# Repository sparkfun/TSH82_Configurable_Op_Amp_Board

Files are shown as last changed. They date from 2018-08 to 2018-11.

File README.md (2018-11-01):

SparkFun Configurable OpAmp Board - TSH82
========================================

SparkFun Configurable OpAmp Board - TSH82

[*SparkFun Configurable OpAmp Board - TSH82 (14874)*](https://www.sparkfun.com/products/14874)

The SparkFun TSH82 Configurable OpAmp Board was designed to give you the best combination of performance and flexibility that we could achieve by giving you two gain stages, each one independently accessible on the header pins. Each stage is natively configured as an inverting amplifier that can also be strung together to expand the capabilities of the OpAmp. With the use of the jumpers on the back of the board, you can configure each stage for non-inverting operation, differential input, and DC input coupling.

Electrically speaking, both stages on this board are identical. The default configuration is inverting with a gain of -4.7 with a bandwidth of almost 10MHz. Input signals are AC coupled, possess an input impedance of 10K with a low frequency cutoff of 15.9Hz. Outputs are also DC coupled, so don’t forget to add a capacitor to the output if you’re running a single-ended supply and need to strip out the DC component. The board will also operate with a single-ended DC power supply of 4.5V to 12V, or a bipolar supply from +/-2.25V to +/-6V.

On the back of the board you’ll find 10 solder jumpers that can be used to change the board’s performance, but nothing there needs to be changed to use it in it’s default state.

Repository Contents
-------------------
* **/Hardware** - Eagle design files (.brd, .sch)
* **/Production** - Production panel files (.brd)

Documentation
--------------
* **[Hookup Guide](https://learn.sparkfun.com/tutorials/tsh82-configurable-opamp-hookup-guide)** - Basic hookup guide for the SparkFun Configurable OpAmp Board - TSH82.
* **[SparkFun Fritzing repo](https://github.com/sparkfun/Fritzing_Parts)** - Fritzing diagrams for SparkFun products.

License Information
-------------------

This product is _**open source**_! 

Please review the LICENSE.md file for license information. 

If you have any questions or concerns on licensing, please contact techsupport@sparkfun.com.

Distributed as-is; no warranty is given.

- Your friends at SparkFun.

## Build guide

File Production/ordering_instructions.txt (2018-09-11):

panel size, 201x143mm
PCB thickness, 1.6mm
number of layers, 2
soldermask color, Red
silkscreen color, White
oz copper, 1oz
finish, HASL lead free
stencils, none
pcs per panel, 40

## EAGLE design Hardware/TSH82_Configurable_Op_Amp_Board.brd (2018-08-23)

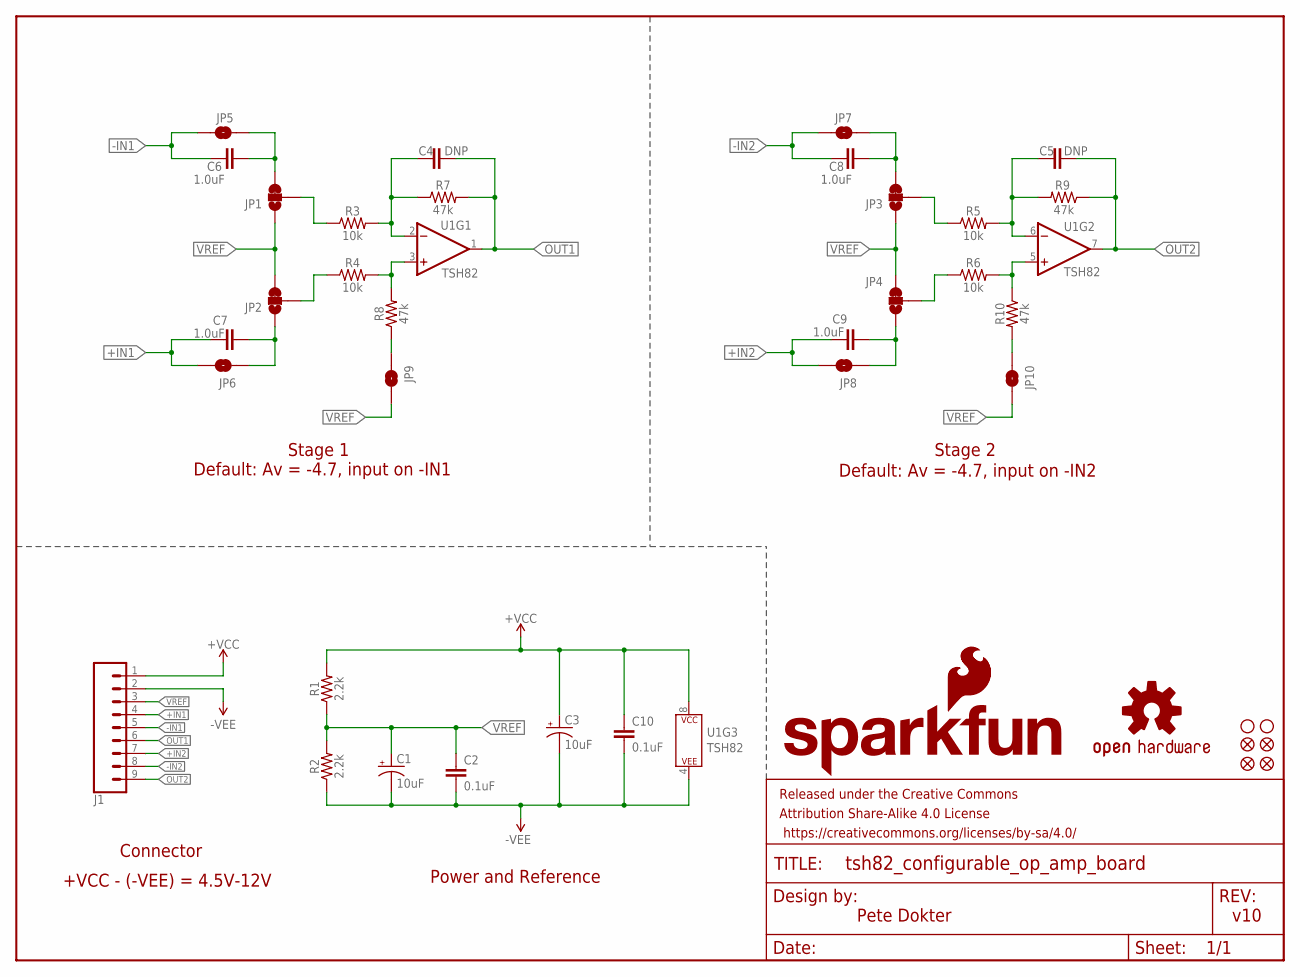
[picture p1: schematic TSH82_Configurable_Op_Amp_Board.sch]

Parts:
C1, C3: 10uF; EIA3216
C2, C10: 0.1uF; 0603
C4, C5: DNP; 0603
C6, C7, C8, C9: 1.0uF; 0603
FD1, FD2, FD3, FD4: FIDUCIALUFIDUCIAL; FIDUCIAL-MICRO
FRAME1: FRAME-LETTER; CREATIVE_COMMONS
H1, H2: STAND-OFF
J1: CONN_09NO_SILK; 1X09_NO_SILK
JP1, JP2, JP3, JP4: JUMPER-SMT_3_1-NC_TRACE_SILK; SMT-JUMPER_3_1-NC_TRACE_SILK
JP5, JP6, JP7, JP8, JP9, JP10: JUMPER-SMT_2_NO_SILK; SMT-JUMPER_2_NO_SILK
LOGO1: SFE_LOGO_FLAME.2_INCH; SFE_LOGO_FLAME_.2
LOGO2: SFE_LOGO_NAME_FLAME.1_INCH; SFE_LOGO_NAME_FLAME_.1
LOGO3: OSHW-LOGOS; OSHW-LOGO-S
R1, R2: 2.2k; 0603
R3, R4, R5, R6: 10k; 0603
R7, R8, R9, R10: 47k; 0603
U1: TSH82; SO08

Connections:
+IN1: C7.1, J1.4, JP6.2
+IN2: C9.1, J1.7, JP8.2
-IN1: C6.1, J1.5, JP5.2
-IN2: C8.1, J1.8, JP7.2
unnamed: C4.1, R3.2, R7.1, U1.2 (-IN)
unnamed: R4.2, R8.2, U1.3 (+IN)
unnamed: JP9.1, R8.1
unnamed: JP1.2, R3.1
unnamed: JP2.2, R4.1
unnamed: C6.2, JP1.3, JP5.1
unnamed: C7.2, JP2.1, JP6.1
unnamed: C8.2, JP3.3, JP7.1
unnamed: JP3.2, R5.1
unnamed: C5.1, R5.2, R9.2, U1.6 (-IN)
unnamed: JP4.2, R6.1
unnamed: C9.2, JP4.1, JP8.1
unnamed: R6.2, R10.1, U1.5 (+IN)
unnamed: JP10.1, R10.2
OUT1: C4.2, J1.6, R7.2, U1.1 (OUT)
OUT2: C5.2, J1.9, R9.1, U1.7 (OUT)
VCC: C3.+, C10.1, J1.1, R1.2, U1.8 (P$V+)
VNEG: C1.-, C2.2, C3.-, C10.2, J1.2, R2.1, U1.4 (P$V-)
VREF: C1.+, C2.1, J1.3, JP1.1, JP2.3, JP3.1, JP4.3, JP9.2, JP10.2, R1.1, R2.2

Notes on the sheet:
Stage 1
Default: Av = -4.7, input on -IN1
Default: Av = -4.7, input on -IN2
Stage 2
Pete Dokter
Connector
Power and Reference
v10
+VCC - (-VEE) = 4.5V-12V

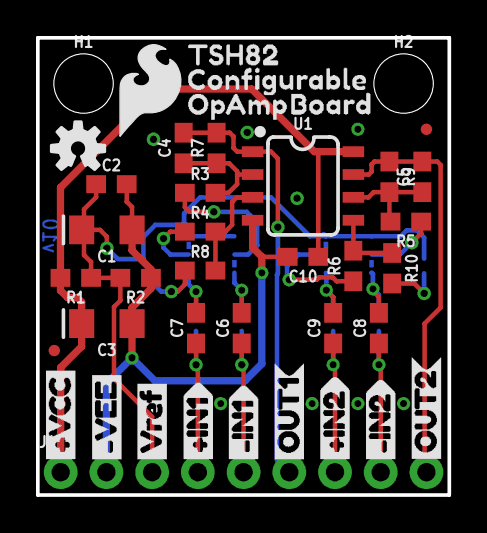
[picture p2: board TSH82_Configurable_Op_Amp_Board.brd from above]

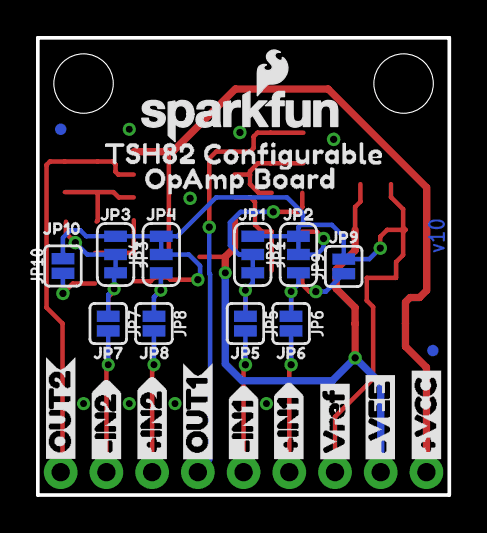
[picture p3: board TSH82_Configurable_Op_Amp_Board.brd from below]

Board: 2 copper layers, 22.9 x 25.4 mm, 78 parts (36 on the bottom side), 23 nets.

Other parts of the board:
U$1, U$2: #VEE1
U$3, U$30: #VCC0
U$4, U$5: VREF6
U$6, U$7: #IN12
U$8, U$9: #IN13
U$10, U$11: OUT17
U$12, U$13: #IN24
U$14, U$16: #IN25
U$15, U$17: OUT28
U$18: JP10
U$19: JP21
U$20: JP32
U$21: JP43
U$22, U$26: TSH820
U$23, U$27: CONFIGURABLE1
U$24, U$28: OPAMP2
U$25, U$29: BOARD3
U$31: JP54
U$32: JP65
U$33: JP76
U$34: JP87
U$35: JP98
U$36: JP109

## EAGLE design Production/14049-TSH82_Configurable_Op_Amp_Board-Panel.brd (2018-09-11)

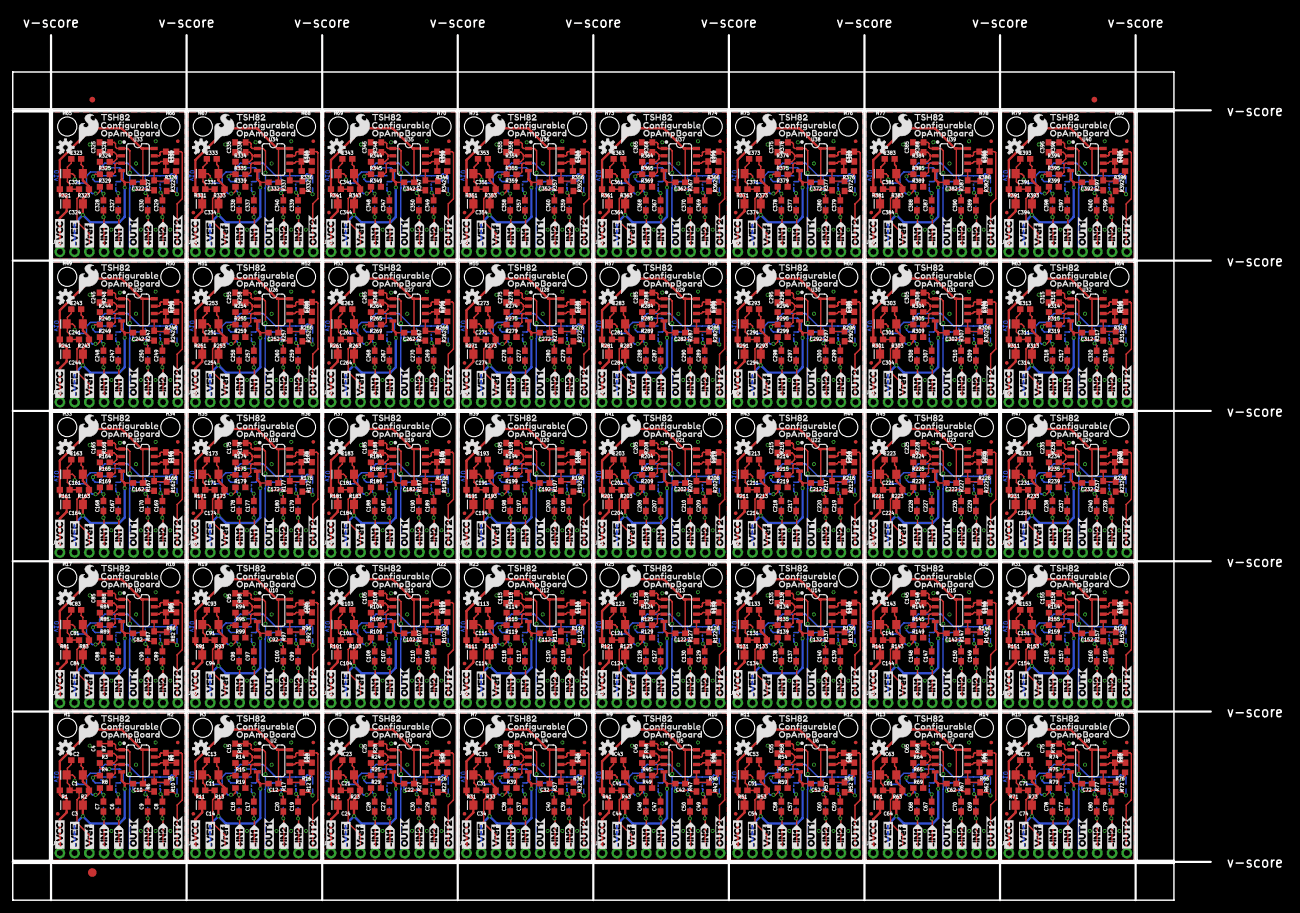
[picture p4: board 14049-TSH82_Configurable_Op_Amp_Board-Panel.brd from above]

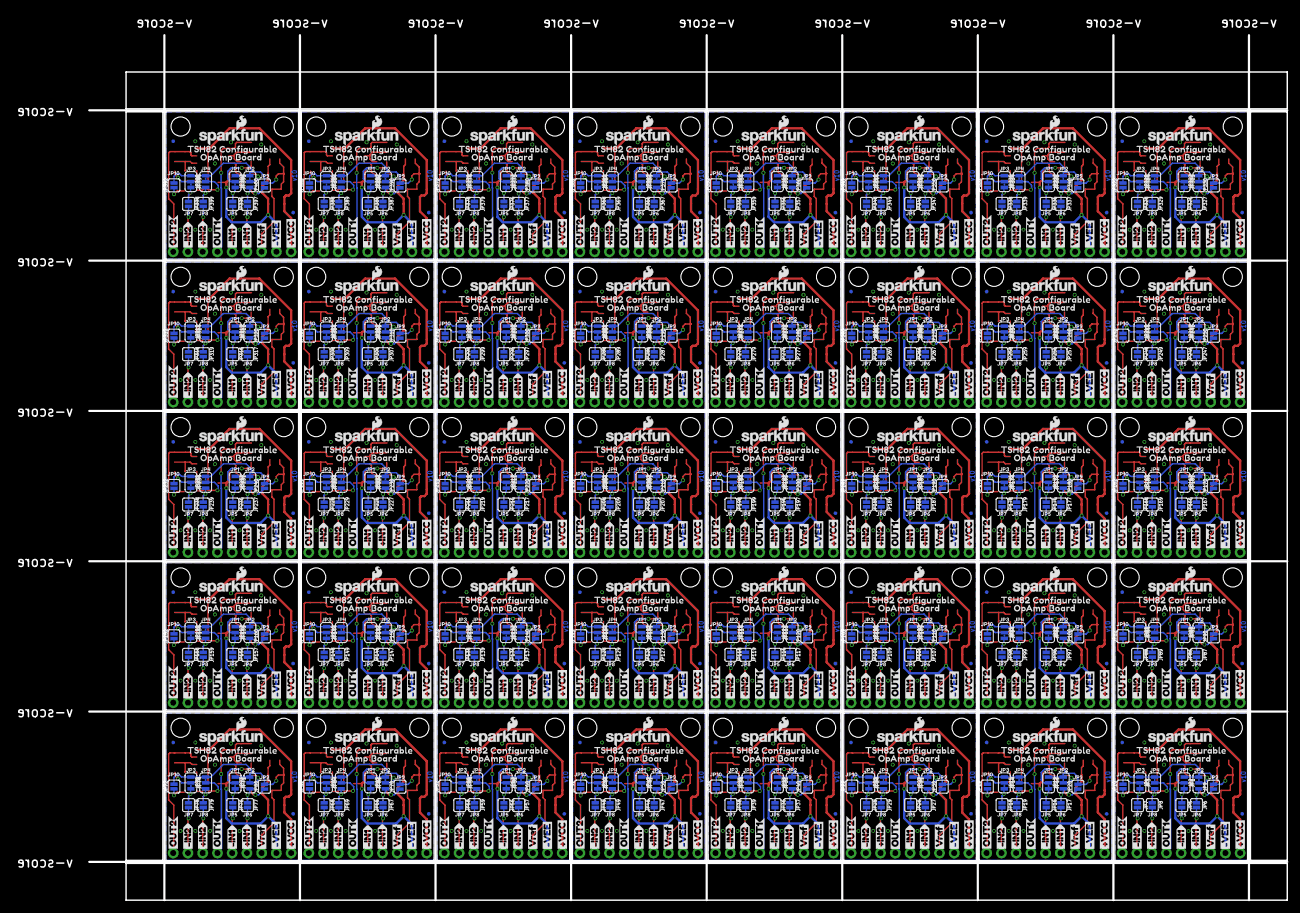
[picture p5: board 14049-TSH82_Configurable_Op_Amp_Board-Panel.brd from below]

Board: 2 copper layers, 206.5 x 149.1 mm, 3083 parts (1440 on the bottom side), 920 nets.

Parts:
C1, C3, C11, C14, C21, C24, C31, C34, C41, C44, C51, C54, C61, C64, C71, C74, C81, C84, C91, C94, C101, C104, C111, C114, C121, C124, C131, C134, C141, C144, C151, C154, C161, C164, C171, C174, C181, C184, C191, C194, C201, C204, C211, C214, C221, C224, C231, C234, C241, C244, C251, C254, C261, C264, C271, C274, C281, C284, C291, C294, C301, C304, C311, C314, C321, C324, C331, C334, C341, C344, C351, C354, C361, C364, C371, C374, C381, C384, C391, C394: 10uF; EIA3216
C2, C10, C12, C13, C22, C23, C32, C33, C42, C43, C52, C53, C62, C63, C72, C73, C82, C83, C92, C93, C102, C103, C112, C113, C122, C123, C132, C133, C142, C143, C152, C153, C162, C163, C172, C173, C182, C183, C192, C193, C202, C203, C212, C213, C222, C223, C232, C233, C242, C243, C252, C253, C262, C263, C272, C273, C282, C283, C292, C293, C302, C303, C312, C313, C322, C323, C332, C333, C342, C343, C352, C353, C362, C363, C372, C373, C382, C383, C392, C393: 0.1uF; 0603
C4, C5, C15, C16, C25, C26, C35, C36, C45, C46, C55, C56, C65, C66, C75, C76, C85, C86, C95, C96, C105, C106, C115, C116, C125, C126, C135, C136, C145, C146, C155, C156, C165, C166, C175, C176, C185, C186, C195, C196, C205, C206, C215, C216, C225, C226, C235, C236, C245, C246, C255, C256, C265, C266, C275, C276, C285, C286, C295, C296, C305, C306, C315, C316, C325, C326, C335, C336, C345, C346, C355, C356, C365, C366, C375, C376, C385, C386, C395, C396: DNP; 0603
C6, C7, C8, C9, C17, C18, C19, C20, C27, C28, C29, C30, C37, C38, C39, C40, C47, C48, C49, C50, C57, C58, C59, C60, C67, C68, C69, C70, C77, C78, C79, C80, C87, C88, C89, C90, C97, C98, C99, C100, C107, C108, C109, C110, C117, C118, C119, C120, C127, C128, C129, C130, C137, C138, C139, C140, C147, C148, C149, C150, C157, C158, C159, C160, C167, C168, C169, C170, C177, C178, C179, C180, C187, C188, C189, C190, C197, C198, C199, C200, C207, C208, C209, C210, C217, C218, C219, C220, C227, C228, C229, C230, C237, C238, C239, C240, C247, C248, C249, C250, C257, C258, C259, C260, C267, C268, C269, C270, C277, C278, C279, C280, C287, C288, C289, C290, C297, C298, C299, C300, C307, C308, C309, C310, C317, C318, C319, C320, C327, C328, C329, C330, C337, C338, C339, C340, C347, C348, C349, C350, C357, C358, C359, C360, C367, C368, C369, C370, C377, C378, C379, C380, C387, C388, C389, C390, C397, C398, C399, C400: 1.0uF; 0603
E$1, E$2: FIDUCIAL-1X2
E$3: FIDUCIAL-1.5X3
FD1, FD2, FD3, FD4, FD5, FD6, FD7, FD8, FD9, FD10, FD11, FD12, FD13, FD14, FD15, FD16, FD17, FD18, FD19, FD20, FD21, FD22, FD23, FD24, FD25, FD26, FD27, FD28, FD29, FD30, FD31, FD32, FD33, FD34, FD35, FD36, FD37, FD38, FD39, FD40, FD41, FD42, FD43, FD44, FD45, FD46, FD47, FD48, FD49, FD50, FD51, FD52, FD53, FD54, FD55, FD56, FD57, FD58, FD59, FD60, FD61, FD62, FD63, FD64, FD65, FD66, FD67, FD68, FD69, FD70, FD71, FD72, FD73, FD74, FD75, FD76, FD77, FD78, FD79, FD80, FD81, FD82, FD83, FD84, FD85, FD86, FD87, FD88, FD89, FD90, FD91, FD92, FD93, FD94, FD95, FD96, FD97, FD98, FD99, FD100, FD101, FD102, FD103, FD104, FD105, FD106, FD107, FD108, FD109, FD110, FD111, FD112, FD113, FD114, FD115, FD116, FD117, FD118, FD119, FD120, FD121, FD122, FD123, FD124, FD125, FD126, FD127, FD128, FD129, FD130, FD131, FD132, FD133, FD134, FD135, FD136, FD137, FD138, FD139, FD140, FD141, FD142, FD143, FD144, FD145, FD146, FD147, FD148, FD149, FD150, FD151, FD152, FD153, FD154, FD155, FD156, FD157, FD158, FD159, FD160: FIDUCIALUFIDUCIAL; FIDUCIAL-MICRO
H1, H2, H3, H4, H5, H6, H7, H8, H9, H10, H11, H12, H13, H14, H15, H16, H17, H18, H19, H20, H21, H22, H23, H24, H25, H26, H27, H28, H29, H30, H31, H32, H33, H34, H35, H36, H37, H38, H39, H40, H41, H42, H43, H44, H45, H46, H47, H48, H49, H50, H51, H52, H53, H54, H55, H56, H57, H58, H59, H60, H61, H62, H63, H64, H65, H66, H67, H68, H69, H70, H71, H72, H73, H74, H75, H76, H77, H78, H79, H80: STAND-OFF
J1, J2, J3, J4, J5, J6, J7, J8, J9, J10, J11, J12, J13, J14, J15, J16, J17, J18, J19, J20, J21, J22, J23, J24, J25, J26, J27, J28, J29, J30, J31, J32, J33, J34, J35, J36, J37, J38, J39, J40: 1X09_NO_SILK
JP1, JP2, JP3, JP4, JP11, JP13, JP14, JP15, JP21, JP23, JP24, JP25, JP31, JP33, JP34, JP35, JP41, JP43, JP44, JP45, JP51, JP53, JP54, JP55, JP61, JP63, JP64, JP65, JP71, JP73, JP74, JP75, JP81, JP83, JP84, JP85, JP91, JP93, JP94, JP95, JP101, JP103, JP104, JP105, JP111, JP113, JP114, JP115, JP121, JP123, JP124, JP125, JP131, JP133, JP134, JP135, JP141, JP143, JP144, JP145, JP151, JP153, JP154, JP155, JP161, JP163, JP164, JP165, JP171, JP173, JP174, JP175, JP181, JP183, JP184, JP185, JP191, JP193, JP194, JP195, JP201, JP203, JP204, JP205, JP211, JP213, JP214, JP215, JP221, JP223, JP224, JP225, JP231, JP233, JP234, JP235, JP241, JP243, JP244, JP245, JP251, JP253, JP254, JP255, JP261, JP263, JP264, JP265, JP271, JP273, JP274, JP275, JP281, JP283, JP284, JP285, JP291, JP293, JP294, JP295, JP301, JP303, JP304, JP305, JP311, JP313, JP314, JP315, JP321, JP323, JP324, JP325, JP331, JP333, JP334, JP335, JP341, JP343, JP344, JP345, JP351, JP353, JP354, JP355, JP361, JP363, JP364, JP365, JP371, JP373, JP374, JP375, JP381, JP383, JP384, JP385, JP391, JP393, JP394, JP395: JUMPER-SMT_3_1-NC_TRACE_SILK; SMT-JUMPER_3_1-NC_TRACE_SILK
JP5, JP6, JP7, JP8, JP9, JP10, JP12, JP16, JP17, JP18, JP19, JP20, JP22, JP26, JP27, JP28, JP29, JP30, JP32, JP36, JP37, JP38, JP39, JP40, JP42, JP46, JP47, JP48, JP49, JP50, JP52, JP56, JP57, JP58, JP59, JP60, JP62, JP66, JP67, JP68, JP69, JP70, JP72, JP76, JP77, JP78, JP79, JP80, JP82, JP86, JP87, JP88, JP89, JP90, JP92, JP96, JP97, JP98, JP99, JP100, JP102, JP106, JP107, JP108, JP109, JP110, JP112, JP116, JP117, JP118, JP119, JP120, JP122, JP126, JP127, JP128, JP129, JP130, JP132, JP136, JP137, JP138, JP139, JP140, JP142, JP146, JP147, JP148, JP149, JP150, JP152, JP156, JP157, JP158, JP159, JP160, JP162, JP166, JP167, JP168, JP169, JP170, JP172, JP176, JP177, JP178, JP179, JP180, JP182, JP186, JP187, JP188, JP189, JP190, JP192, JP196, JP197, JP198, JP199, JP200, JP202, JP206, JP207, JP208, JP209, JP210, JP212, JP216, JP217, JP218, JP219, JP220, JP222, JP226, JP227, JP228, JP229, JP230, JP232, JP236, JP237, JP238, JP239, JP240, JP242, JP246, JP247, JP248, JP249, JP250, JP252, JP256, JP257, JP258, JP259, JP260, JP262, JP266, JP267, JP268, JP269, JP270, JP272, JP276, JP277, JP278, JP279, JP280, JP282, JP286, JP287, JP288, JP289, JP290, JP292, JP296, JP297, JP298, JP299, JP300, JP302, JP306, JP307, JP308, JP309, JP310, JP312, JP316, JP317, JP318, JP319, JP320, JP322, JP326, JP327, JP328, JP329, JP330, JP332, JP336, JP337, JP338, JP339, JP340, JP342, JP346, JP347, JP348, JP349, JP350, JP352, JP356, JP357, JP358, JP359, JP360, JP362, JP366, JP367, JP368, JP369, JP370, JP372, JP376, JP377, JP378, JP379, JP380, JP382, JP386, JP387, JP388, JP389, JP390, JP392, JP396, JP397, JP398, JP399, JP400: JUMPER-SMT_2_NO_SILK; SMT-JUMPER_2_NO_SILK
LOGO1, LOGO4, LOGO7, LOGO10, LOGO13, LOGO16, LOGO19, LOGO22, LOGO25, LOGO28, LOGO31, LOGO34, LOGO37, LOGO40, LOGO43, LOGO46, LOGO49, LOGO52, LOGO55, LOGO58, LOGO61, LOGO64, LOGO67, LOGO70, LOGO73, LOGO76, LOGO79, LOGO82, LOGO85, LOGO88, LOGO91, LOGO94, LOGO97, LOGO100, LOGO103, LOGO106, LOGO109, LOGO112, LOGO115, LOGO118: SFE_LOGO_FLAME.2_INCH; SFE_LOGO_FLAME_.2
LOGO2, LOGO5, LOGO8, LOGO11, LOGO14, LOGO17, LOGO20, LOGO23, LOGO26, LOGO29, LOGO32, LOGO35, LOGO38, LOGO41, LOGO44, LOGO47, LOGO50, LOGO53, LOGO56, LOGO59, LOGO62, LOGO65, LOGO68, LOGO71, LOGO74, LOGO77, LOGO80, LOGO83, LOGO86, LOGO89, LOGO92, LOGO95, LOGO98, LOGO101, LOGO104, LOGO107, LOGO110, LOGO113, LOGO116, LOGO119: SFE_LOGO_NAME_FLAME.1_INCH; SFE_LOGO_NAME_FLAME_.1
LOGO3, LOGO6, LOGO9, LOGO12, LOGO15, LOGO18, LOGO21, LOGO24, LOGO27, LOGO30, LOGO33, LOGO36, LOGO39, LOGO42, LOGO45, LOGO48, LOGO51, LOGO54, LOGO57, LOGO60, LOGO63, LOGO66, LOGO69, LOGO72, LOGO75, LOGO78, LOGO81, LOGO84, LOGO87, LOGO90, LOGO93, LOGO96, LOGO99, LOGO102, LOGO105, LOGO108, LOGO111, LOGO114, LOGO117, LOGO120: OSHW-LOGOS; OSHW-LOGO-S
R1, R2, R11, R13, R21, R23, R31, R33, R41, R43, R51, R53, R61, R63, R71, R73, R81, R83, R91, R93, R101, R103, R111, R113, R121, R123, R131, R133, R141, R143, R151, R153, R161, R163, R171, R173, R181, R183, R191, R193, R201, R203, R211, R213, R221, R223, R231, R233, R241, R243, R251, R253, R261, R263, R271, R273, R281, R283, R291, R293, R301, R303, R311, R313, R321, R323, R331, R333, R341, R343, R351, R353, R361, R363, R371, R373, R381, R383, R391, R393: 2.2k; 0603
R3, R4, R5, R6, R14, R15, R16, R17, R24, R25, R26, R27, R34, R35, R36, R37, R44, R45, R46, R47, R54, R55, R56, R57, R64, R65, R66, R67, R74, R75, R76, R77, R84, R85, R86, R87, R94, R95, R96, R97, R104, R105, R106, R107, R114, R115, R116, R117, R124, R125, R126, R127, R134, R135, R136, R137, R144, R145, R146, R147, R154, R155, R156, R157, R164, R165, R166, R167, R174, R175, R176, R177, R184, R185, R186, R187, R194, R195, R196, R197, R204, R205, R206, R207, R214, R215, R216, R217, R224, R225, R226, R227, R234, R235, R236, R237, R244, R245, R246, R247, R254, R255, R256, R257, R264, R265, R266, R267, R274, R275, R276, R277, R284, R285, R286, R287, R294, R295, R296, R297, R304, R305, R306, R307, R314, R315, R316, R317, R324, R325, R326, R327, R334, R335, R336, R337, R344, R345, R346, R347, R354, R355, R356, R357, R364, R365, R366, R367, R374, R375, R376, R377, R384, R385, R386, R387, R394, R395, R396, R397: 10k; 0603
R7, R8, R9, R10, R12, R18, R19, R20, R22, R28, R29, R30, R32, R38, R39, R40, R42, R48, R49, R50, R52, R58, R59, R60, R62, R68, R69, R70, R72, R78, R79, R80, R82, R88, R89, R90, R92, R98, R99, R100, R102, R108, R109, R110, R112, R118, R119, R120, R122, R128, R129, R130, R132, R138, R139, R140, R142, R148, R149, R150, R152, R158, R159, R160, R162, R168, R169, R170, R172, R178, R179, R180, R182, R188, R189, R190, R192, R198, R199, R200, R202, R208, R209, R210, R212, R218, R219, R220, R222, R228, R229, R230, R232, R238, R239, R240, R242, R248, R249, R250, R252, R258, R259, R260, R262, R268, R269, R270, R272, R278, R279, R280, R282, R288, R289, R290, R292, R298, R299, R300, R302, R308, R309, R310, R312, R318, R319, R320, R322, R328, R329, R330, R332, R338, R339, R340, R342, R348, R349, R350, R352, R358, R359, R360, R362, R368, R369, R370, R372, R378, R379, R380, R382, R388, R389, R390, R392, R398, R399, R400: 47k; 0603
U1, U2, U3, U4, U5, U6, U7, U8, U9, U10, U11, U12, U13, U14, U15, U16, U17, U18, U19, U20, U21, U22, U23, U24, U25, U26, U27, U28, U29, U30, U31, U32, U33, U34, U35, U36, U37, U38, U39, U40: TSH82; SO08
U$1, U$2, U$46, U$47, U$82, U$83, U$118, U$119, U$154, U$155, U$190, U$191, U$226, U$227, U$262, U$263, U$298, U$299, U$334, U$335, U$370, U$371, U$406, U$407, U$442, U$443, U$478, U$479, U$514, U$515, U$550, U$551, U$586, U$587, U$622, U$623, U$658, U$659, U$694, U$695, U$730, U$731, U$766, U$767, U$802, U$803, U$838, U$839, U$874, U$875, U$910, U$911, U$946, U$947, U$982, U$983, U$1018, U$1019, U$1054, U$1055, U$1090, U$1091, U$1126, U$1127, U$1162, U$1163, U$1198, U$1199, U$1234, U$1235, U$1270, U$1271, U$1306, U$1307, U$1342, U$1343, U$1378, U$1379, U$1414, U$1415: #VEE1
U$3, U$30, U$45, U$48, U$81, U$84, U$117, U$120, U$153, U$156, U$189, U$192, U$225, U$228, U$261, U$264, U$297, U$300, U$333, U$336, U$369, U$372, U$405, U$408, U$441, U$444, U$477, U$480, U$513, U$516, U$549, U$552, U$585, U$588, U$621, U$624, U$657, U$660, U$693, U$696, U$729, U$732, U$765, U$768, U$801, U$804, U$837, U$840, U$873, U$876, U$909, U$912, U$945, U$948, U$981, U$984, U$1017, U$1020, U$1053, U$1056, U$1089, U$1092, U$1125, U$1128, U$1161, U$1164, U$1197, U$1200, U$1233, U$1236, U$1269, U$1272, U$1305, U$1308, U$1341, U$1344, U$1377, U$1380, U$1413, U$1416: #VCC0
U$4, U$5, U$49, U$50, U$85, U$86, U$121, U$122, U$157, U$158, U$193, U$194, U$229, U$230, U$265, U$266, U$301, U$302, U$337, U$338, U$373, U$374, U$409, U$410, U$445, U$446, U$481, U$482, U$517, U$518, U$553, U$554, U$589, U$590, U$625, U$626, U$661, U$662, U$697, U$698, U$733, U$734, U$769, U$770, U$805, U$806, U$841, U$842, U$877, U$878, U$913, U$914, U$949, U$950, U$985, U$986, U$1021, U$1022, U$1057, U$1058, U$1093, U$1094, U$1129, U$1130, U$1165, U$1166, U$1201, U$1202, U$1237, U$1238, U$1273, U$1274, U$1309, U$1310, U$1345, U$1346, U$1381, U$1382, U$1417, U$1418: VREF6
U$6, U$7, U$51, U$52, U$87, U$88, U$123, U$124, U$159, U$160, U$195, U$196, U$231, U$232, U$267, U$268, U$303, U$304, U$339, U$340, U$375, U$376, U$411, U$412, U$447, U$448, U$483, U$484, U$519, U$520, U$555, U$556, U$591, U$592, U$627, U$628, U$663, U$664, U$699, U$700, U$735, U$736, U$771, U$772, U$807, U$808, U$843, U$844, U$879, U$880, U$915, U$916, U$951, U$952, U$987, U$988, U$1023, U$1024, U$1059, U$1060, U$1095, U$1096, U$1131, U$1132, U$1167, U$1168, U$1203, U$1204, U$1239, U$1240, U$1275, U$1276, U$1311, U$1312, U$1347, U$1348, U$1383, U$1384, U$1419, U$1420: #IN12
U$8, U$9, U$53, U$54, U$89, U$90, U$125, U$126, U$161, U$162, U$197, U$198, U$233, U$234, U$269, U$270, U$305, U$306, U$341, U$342, U$377, U$378, U$413, U$414, U$449, U$450, U$485, U$486, U$521, U$522, U$557, U$558, U$593, U$594, U$629, U$630, U$665, U$666, U$701, U$702, U$737, U$738, U$773, U$774, U$809, U$810, U$845, U$846, U$881, U$882, U$917, U$918, U$953, U$954, U$989, U$990, U$1025, U$1026, U$1061, U$1062, U$1097, U$1098, U$1133, U$1134, U$1169, U$1170, U$1205, U$1206, U$1241, U$1242, U$1277, U$1278, U$1313, U$1314, U$1349, U$1350, U$1385, U$1386, U$1421, U$1422: #IN13
U$10, U$11, U$55, U$56, U$91, U$92, U$127, U$128, U$163, U$164, U$199, U$200, U$235, U$236, U$271, U$272, U$307, U$308, U$343, U$344, U$379, U$380, U$415, U$416, U$451, U$452, U$487, U$488, U$523, U$524, U$559, U$560, U$595, U$596, U$631, U$632, U$667, U$668, U$703, U$704, U$739, U$740, U$775, U$776, U$811, U$812, U$847, U$848, U$883, U$884, U$919, U$920, U$955, U$956, U$991, U$992, U$1027, U$1028, U$1063, U$1064, U$1099, U$1100, U$1135, U$1136, U$1171, U$1172, U$1207, U$1208, U$1243, U$1244, U$1279, U$1280, U$1315, U$1316, U$1351, U$1352, U$1387, U$1388, U$1423, U$1424: OUT17
U$12, U$13, U$57, U$58, U$93, U$94, U$129, U$130, U$165, U$166, U$201, U$202, U$237, U$238, U$273, U$274, U$309, U$310, U$345, U$346, U$381, U$382, U$417, U$418, U$453, U$454, U$489, U$490, U$525, U$526, U$561, U$562, U$597, U$598, U$633, U$634, U$669, U$670, U$705, U$706, U$741, U$742, U$777, U$778, U$813, U$814, U$849, U$850, U$885, U$886, U$921, U$922, U$957, U$958, U$993, U$994, U$1029, U$1030, U$1065, U$1066, U$1101, U$1102, U$1137, U$1138, U$1173, U$1174, U$1209, U$1210, U$1245, U$1246, U$1281, U$1282, U$1317, U$1318, U$1353, U$1354, U$1389, U$1390, U$1425, U$1426: #IN24
U$14, U$16, U$59, U$60, U$95, U$96, U$131, U$132, U$167, U$168, U$203, U$204, U$239, U$240, U$275, U$276, U$311, U$312, U$347, U$348, U$383, U$384, U$419, U$420, U$455, U$456, U$491, U$492, U$527, U$528, U$563, U$564, U$599, U$600, U$635, U$636, U$671, U$672, U$707, U$708, U$743, U$744, U$779, U$780, U$815, U$816, U$851, U$852, U$887, U$888, U$923, U$924, U$959, U$960, U$995, U$996, U$1031, U$1032, U$1067, U$1068, U$1103, U$1104, U$1139, U$1140, U$1175, U$1176, U$1211, U$1212, U$1247, U$1248, U$1283, U$1284, U$1319, U$1320, U$1355, U$1356, U$1391, U$1392, U$1427, U$1428: #IN25
U$15, U$17, U$61, U$62, U$97, U$98, U$133, U$134, U$169, U$170, U$205, U$206, U$241, U$242, U$277, U$278, U$313, U$314, U$349, U$350, U$385, U$386, U$421, U$422, U$457, U$458, U$493, U$494, U$529, U$530, U$565, U$566, U$601, U$602, U$637, U$638, U$673, U$674, U$709, U$710, U$745, U$746, U$781, U$782, U$817, U$818, U$853, U$854, U$889, U$890, U$925, U$926, U$961, U$962, U$997, U$998, U$1033, U$1034, U$1069, U$1070, U$1105, U$1106, U$1141, U$1142, U$1177, U$1178, U$1213, U$1214, U$1249, U$1250, U$1285, U$1286, U$1321, U$1322, U$1357, U$1358, U$1393, U$1394, U$1429, U$1430: OUT28
U$18, U$63, U$99, U$135, U$171, U$207, U$243, U$279, U$315, U$351, U$387, U$423, U$459, U$495, U$531, U$567, U$603, U$639, U$675, U$711, U$747, U$783, U$819, U$855, U$891, U$927, U$963, U$999, U$1035, U$1071, U$1107, U$1143, U$1179, U$1215, U$1251, U$1287, U$1323, U$1359, U$1395, U$1431: JP10
U$19, U$64, U$100, U$136, U$172, U$208, U$244, U$280, U$316, U$352, U$388, U$424, U$460, U$496, U$532, U$568, U$604, U$640, U$676, U$712, U$748, U$784, U$820, U$856, U$892, U$928, U$964, U$1000, U$1036, U$1072, U$1108, U$1144, U$1180, U$1216, U$1252, U$1288, U$1324, U$1360, U$1396, U$1432: JP21
U$20, U$65, U$101, U$137, U$173, U$209, U$245, U$281, U$317, U$353, U$389, U$425, U$461, U$497, U$533, U$569, U$605, U$641, U$677, U$713, U$749, U$785, U$821, U$857, U$893, U$929, U$965, U$1001, U$1037, U$1073, U$1109, U$1145, U$1181, U$1217, U$1253, U$1289, U$1325, U$1361, U$1397, U$1433: JP32
U$21, U$66, U$102, U$138, U$174, U$210, U$246, U$282, U$318, U$354, U$390, U$426, U$462, U$498, U$534, U$570, U$606, U$642, U$678, U$714, U$750, U$786, U$822, U$858, U$894, U$930, U$966, U$1002, U$1038, U$1074, U$1110, U$1146, U$1182, U$1218, U$1254, U$1290, U$1326, U$1362, U$1398, U$1434: JP43
U$22, U$26, U$37, U$41, U$73, U$77, U$109, U$113, U$145, U$149, U$181, U$185, U$217, U$221, U$253, U$257, U$289, U$293, U$325, U$329, U$361, U$365, U$397, U$401, U$433, U$437, U$469, U$473, U$505, U$509, U$541, U$545, U$577, U$581, U$613, U$617, U$649, U$653, U$685, U$689, U$721, U$725, U$757, U$761, U$793, U$797, U$829, U$833, U$865, U$869, U$901, U$905, U$937, U$941, U$973, U$977, U$1009, U$1013, U$1045, U$1049, U$1081, U$1085, U$1117, U$1121, U$1153, U$1157, U$1189, U$1193, U$1225, U$1229, U$1261, U$1265, U$1297, U$1301, U$1333, U$1337, U$1369, U$1373, U$1405, U$1409: TSH820
U$23, U$27, U$38, U$42, U$74, U$78, U$110, U$114, U$146, U$150, U$182, U$186, U$218, U$222, U$254, U$258, U$290, U$294, U$326, U$330, U$362, U$366, U$398, U$402, U$434, U$438, U$470, U$474, U$506, U$510, U$542, U$546, U$578, U$582, U$614, U$618, U$650, U$654, U$686, U$690, U$722, U$726, U$758, U$762, U$794, U$798, U$830, U$834, U$866, U$870, U$902, U$906, U$938, U$942, U$974, U$978, U$1010, U$1014, U$1046, U$1050, U$1082, U$1086, U$1118, U$1122, U$1154, U$1158, U$1190, U$1194, U$1226, U$1230, U$1262, U$1266, U$1298, U$1302, U$1334, U$1338, U$1370, U$1374, U$1406, U$1410: CONFIGURABLE1
U$24, U$28, U$39, U$43, U$75, U$79, U$111, U$115, U$147, U$151, U$183, U$187, U$219, U$223, U$255, U$259, U$291, U$295, U$327, U$331, U$363, U$367, U$399, U$403, U$435, U$439, U$471, U$475, U$507, U$511, U$543, U$547, U$579, U$583, U$615, U$619, U$651, U$655, U$687, U$691, U$723, U$727, U$759, U$763, U$795, U$799, U$831, U$835, U$867, U$871, U$903, U$907, U$939, U$943, U$975, U$979, U$1011, U$1015, U$1047, U$1051, U$1083, U$1087, U$1119, U$1123, U$1155, U$1159, U$1191, U$1195, U$1227, U$1231, U$1263, U$1267, U$1299, U$1303, U$1335, U$1339, U$1371, U$1375, U$1407, U$1411: OPAMP2
U$25, U$29, U$40, U$44, U$76, U$80, U$112, U$116, U$148, U$152, U$184, U$188, U$220, U$224, U$256, U$260, U$292, U$296, U$328, U$332, U$364, U$368, U$400, U$404, U$436, U$440, U$472, U$476, U$508, U$512, U$544, U$548, U$580, U$584, U$616, U$620, U$652, U$656, U$688, U$692, U$724, U$728, U$760, U$764, U$796, U$800, U$832, U$836, U$868, U$872, U$904, U$908, U$940, U$944, U$976, U$980, U$1012, U$1016, U$1048, U$1052, U$1084, U$1088, U$1120, U$1124, U$1156, U$1160, U$1192, U$1196, U$1228, U$1232, U$1264, U$1268, U$1300, U$1304, U$1336, U$1340, U$1372, U$1376, U$1408, U$1412: BOARD3
U$31, U$67, U$103, U$139, U$175, U$211, U$247, U$283, U$319, U$355, U$391, U$427, U$463, U$499, U$535, U$571, U$607, U$643, U$679, U$715, U$751, U$787, U$823, U$859, U$895, U$931, U$967, U$1003, U$1039, U$1075, U$1111, U$1147, U$1183, U$1219, U$1255, U$1291, U$1327, U$1363, U$1399, U$1435: JP54
U$32, U$68, U$104, U$140, U$176, U$212, U$248, U$284, U$320, U$356, U$392, U$428, U$464, U$500, U$536, U$572, U$608, U$644, U$680, U$716, U$752, U$788, U$824, U$860, U$896, U$932, U$968, U$1004, U$1040, U$1076, U$1112, U$1148, U$1184, U$1220, U$1256, U$1292, U$1328, U$1364, U$1400, U$1436: JP65
U$33, U$69, U$105, U$141, U$177, U$213, U$249, U$285, U$321, U$357, U$393, U$429, U$465, U$501, U$537, U$573, U$609, U$645, U$681, U$717, U$753, U$789, U$825, U$861, U$897, U$933, U$969, U$1005, U$1041, U$1077, U$1113, U$1149, U$1185, U$1221, U$1257, U$1293, U$1329, U$1365, U$1401, U$1437: JP76
U$34, U$70, U$106, U$142, U$178, U$214, U$250, U$286, U$322, U$358, U$394, U$430, U$466, U$502, U$538, U$574, U$610, U$646, U$682, U$718, U$754, U$790, U$826, U$862, U$898, U$934, U$970, U$1006, U$1042, U$1078, U$1114, U$1150, U$1186, U$1222, U$1258, U$1294, U$1330, U$1366, U$1402, U$1438: JP87
U$35, U$71, U$107, U$143, U$179, U$215, U$251, U$287, U$323, U$359, U$395, U$431, U$467, U$503, U$539, U$575, U$611, U$647, U$683, U$719, U$755, U$791, U$827, U$863, U$899, U$935, U$971, U$1007, U$1043, U$1079, U$1115, U$1151, U$1187, U$1223, U$1259, U$1295, U$1331, U$1367, U$1403, U$1439: JP98
U$36, U$72, U$108, U$144, U$180, U$216, U$252, U$288, U$324, U$360, U$396, U$432, U$468, U$504, U$540, U$576, U$612, U$648, U$684, U$720, U$756, U$792, U$828, U$864, U$900, U$936, U$972, U$1008, U$1044, U$1080, U$1116, U$1152, U$1188, U$1224, U$1260, U$1296, U$1332, U$1368, U$1404, U$1440: JP109

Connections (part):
+IN1: C7.1, J1.4, JP6.2
+IN2: C9.1, J1.7, JP8.2
+IN3: C18.1, J2.4, JP17.2
+IN4: C20.1, J2.7, JP19.2
+IN5: C28.1, J3.4, JP27.2
+IN6: C30.1, J3.7, JP29.2
+IN7: C38.1, J4.4, JP37.2
+IN8: C40.1, J4.7, JP39.2
+IN9: C48.1, J5.4, JP47.2
+IN10: C50.1, J5.7, JP49.2
+IN11: C58.1, J6.4, JP57.2
+IN12: C60.1, J6.7, JP59.2
+IN13: C68.1, J7.4, JP67.2
+IN14: C70.1, J7.7, JP69.2
+IN15: C78.1, J8.4, JP77.2
+IN16: C80.1, J8.7, JP79.2
+IN17: C88.1, J9.4, JP87.2
+IN18: C90.1, J9.7, JP89.2
+IN19: C98.1, J10.4, JP97.2
+IN20: C100.1, J10.7, JP99.2
+IN21: C108.1, J11.4, JP107.2
+IN22: C110.1, J11.7, JP109.2
+IN23: C118.1, J12.4, JP117.2
+IN24: C120.1, J12.7, JP119.2
+IN25: C128.1, J13.4, JP127.2
+IN26: C130.1, J13.7, JP129.2
+IN27: C138.1, J14.4, JP137.2
+IN28: C140.1, J14.7, JP139.2
+IN29: C148.1, J15.4, JP147.2
+IN30: C150.1, J15.7, JP149.2
+IN31: C158.1, J16.4, JP157.2
+IN32: C160.1, J16.7, JP159.2
+IN33: C168.1, J17.4, JP167.2
+IN34: C170.1, J17.7, JP169.2
+IN35: C178.1, J18.4, JP177.2
+IN36: C180.1, J18.7, JP179.2
+IN37: C188.1, J19.4, JP187.2
+IN38: C190.1, J19.7, JP189.2
+IN39: C198.1, J20.4, JP197.2
+IN40: C200.1, J20.7, JP199.2
+IN41: C208.1, J21.4, JP207.2
+IN42: C210.1, J21.7, JP209.2
+IN43: C218.1, J22.4, JP217.2
+IN44: C220.1, J22.7, JP219.2
+IN45: C228.1, J23.4, JP227.2
+IN46: C230.1, J23.7, JP229.2
+IN47: C238.1, J24.4, JP237.2
+IN48: C240.1, J24.7, JP239.2
+IN49: C248.1, J25.4, JP247.2
+IN50: C250.1, J25.7, JP249.2
+IN51: C258.1, J26.4, JP257.2
+IN52: C260.1, J26.7, JP259.2
+IN53: C268.1, J27.4, JP267.2
+IN54: C270.1, J27.7, JP269.2
+IN55: C278.1, J28.4, JP277.2
+IN56: C280.1, J28.7, JP279.2
+IN57: C288.1, J29.4, JP287.2
+IN58: C290.1, J29.7, JP289.2
+IN59: C298.1, J30.4, JP297.2
+IN60: C300.1, J30.7, JP299.2
+IN61: C308.1, J31.4, JP307.2
+IN62: C310.1, J31.7, JP309.2
+IN63: C318.1, J32.4, JP317.2
+IN64: C320.1, J32.7, JP319.2
+IN65: C328.1, J33.4, JP327.2
+IN66: C330.1, J33.7, JP329.2
+IN67: C338.1, J34.4, JP337.2
+IN68: C340.1, J34.7, JP339.2
+IN69: C348.1, J35.4, JP347.2
+IN70: C350.1, J35.7, JP349.2
+IN71: C358.1, J36.4, JP357.2
+IN72: C360.1, J36.7, JP359.2
+IN73: C368.1, J37.4, JP367.2
+IN74: C370.1, J37.7, JP369.2
+IN75: C378.1, J38.4, JP377.2
+IN76: C380.1, J38.7, JP379.2
+IN77: C388.1, J39.4, JP387.2
+IN78: C390.1, J39.7, JP389.2
+IN79: C398.1, J40.4, JP397.2
+IN80: C400.1, J40.7, JP399.2
-IN1: C6.1, J1.5, JP5.2
-IN2: C8.1, J1.8, JP7.2
-IN3: C17.1, J2.5, JP16.2
-IN4: C19.1, J2.8, JP18.2
-IN5: C27.1, J3.5, JP26.2
-IN6: C29.1, J3.8, JP28.2
-IN7: C37.1, J4.5, JP36.2
-IN8: C39.1, J4.8, JP38.2
-IN9: C47.1, J5.5, JP46.2
-IN10: C49.1, J5.8, JP48.2
-IN11: C57.1, J6.5, JP56.2
-IN12: C59.1, J6.8, JP58.2
-IN13: C67.1, J7.5, JP66.2
-IN14: C69.1, J7.8, JP68.2
-IN15: C77.1, J8.5, JP76.2
-IN16: C79.1, J8.8, JP78.2
-IN17: C87.1, J9.5, JP86.2
-IN18: C89.1, J9.8, JP88.2
-IN19: C97.1, J10.5, JP96.2
-IN20: C99.1, J10.8, JP98.2
-IN21: C107.1, J11.5, JP106.2
-IN22: C109.1, J11.8, JP108.2
-IN23: C117.1, J12.5, JP116.2
-IN24: C119.1, J12.8, JP118.2
-IN25: C127.1, J13.5, JP126.2
-IN26: C129.1, J13.8, JP128.2
-IN27: C137.1, J14.5, JP136.2
-IN28: C139.1, J14.8, JP138.2
-IN29: C147.1, J15.5, JP146.2
-IN30: C149.1, J15.8, JP148.2
-IN31: C157.1, J16.5, JP156.2
-IN32: C159.1, J16.8, JP158.2
-IN33: C167.1, J17.5, JP166.2
-IN34: C169.1, J17.8, JP168.2
-IN35: C177.1, J18.5, JP176.2
-IN36: C179.1, J18.8, JP178.2
-IN37: C187.1, J19.5, JP186.2
-IN38: C189.1, J19.8, JP188.2
-IN39: C197.1, J20.5, JP196.2
-IN40: C199.1, J20.8, JP198.2
-IN41: C207.1, J21.5, JP206.2
-IN42: C209.1, J21.8, JP208.2
-IN43: C217.1, J22.5, JP216.2
-IN44: C219.1, J22.8, JP218.2
-IN45: C227.1, J23.5, JP226.2
-IN46: C229.1, J23.8, JP228.2
-IN47: C237.1, J24.5, JP236.2
-IN48: C239.1, J24.8, JP238.2
-IN49: C247.1, J25.5, JP246.2
-IN50: C249.1, J25.8, JP248.2
-IN51: C257.1, J26.5, JP256.2
-IN52: C259.1, J26.8, JP258.2
-IN53: C267.1, J27.5, JP266.2
-IN54: C269.1, J27.8, JP268.2
-IN55: C277.1, J28.5, JP276.2
-IN56: C279.1, J28.8, JP278.2
-IN57: C287.1, J29.5, JP286.2
-IN58: C289.1, J29.8, JP288.2
-IN59: C297.1, J30.5, JP296.2
-IN60: C299.1, J30.8, JP298.2
-IN61: C307.1, J31.5, JP306.2
-IN62: C309.1, J31.8, JP308.2
-IN63: C317.1, J32.5, JP316.2
-IN64: C319.1, J32.8, JP318.2
-IN65: C327.1, J33.5, JP326.2
-IN66: C329.1, J33.8, JP328.2
-IN67: C337.1, J34.5, JP336.2
-IN68: C339.1, J34.8, JP338.2
-IN69: C347.1, J35.5, JP346.2
-IN70: C349.1, J35.8, JP348.2
-IN71: C357.1, J36.5, JP356.2
-IN72: C359.1, J36.8, JP358.2
-IN73: C367.1, J37.5, JP366.2
-IN74: C369.1, J37.8, JP368.2
-IN75: C377.1, J38.5, JP376.2
-IN76: C379.1, J38.8, JP378.2
-IN77: C387.1, J39.5, JP386.2
-IN78: C389.1, J39.8, JP388.2
-IN79: C397.1, J40.5, JP396.2
-IN80: C399.1, J40.8, JP398.2
unnamed: C4.1, R3.2, R7.1, U1.2
unnamed: R4.2, R8.2, U1.3
unnamed: JP9.1, R8.1
unnamed: JP1.2, R3.1
unnamed: JP2.2, R4.1
unnamed: C6.2, JP1.3, JP5.1
unnamed: C7.2, JP2.1, JP6.1
unnamed: C15.1, R14.2, R18.1, U2.2
unnamed: C8.2, JP3.3, JP7.1
unnamed: JP3.2, R5.1
unnamed: C5.1, R5.2, R9.2, U1.6
unnamed: R15.2, R19.2, U2.3
unnamed: JP20.1, R19.1
unnamed: JP11.2, R14.1
unnamed: JP13.2, R15.1
unnamed: JP4.2, R6.1
unnamed: C9.2, JP4.1, JP8.1
unnamed: C17.2, JP11.3, JP16.1
unnamed: R6.2, R10.1, U1.5
unnamed: JP10.1, R10.2
unnamed: C18.2, JP13.1, JP17.1
unnamed: C19.2, JP14.3, JP18.1
unnamed: JP14.2, R16.1
unnamed: C16.1, R16.2, R20.2, U2.6
unnamed: JP15.2, R17.1
unnamed: C20.2, JP15.1, JP19.1
unnamed: R12.1, R17.2, U2.5
unnamed: JP12.1, R12.2
unnamed: C25.1, R24.2, R28.1, U3.2
unnamed: R25.2, R29.2, U3.3
unnamed: JP30.1, R29.1
unnamed: JP21.2, R24.1
unnamed: JP23.2, R25.1
unnamed: C27.2, JP21.3, JP26.1
unnamed: C28.2, JP23.1, JP27.1
unnamed: C29.2, JP24.3, JP28.1
unnamed: JP24.2, R26.1
unnamed: C26.1, R26.2, R30.2, U3.6
unnamed: JP25.2, R27.1
unnamed: C30.2, JP25.1, JP29.1
unnamed: R22.1, R27.2, U3.5
unnamed: JP22.1, R22.2
unnamed: C35.1, R34.2, R38.1, U4.2
unnamed: R35.2, R39.2, U4.3
unnamed: JP40.1, R39.1
unnamed: JP31.2, R34.1
unnamed: JP33.2, R35.1
unnamed: C37.2, JP31.3, JP36.1
unnamed: C38.2, JP33.1, JP37.1
unnamed: C39.2, JP34.3, JP38.1
unnamed: JP34.2, R36.1
unnamed: C36.1, R36.2, R40.2, U4.6
unnamed: JP35.2, R37.1
unnamed: C40.2, JP35.1, JP39.1
unnamed: R32.1, R37.2, U4.5
unnamed: JP32.1, R32.2
unnamed: C45.1, R44.2, R48.1, U5.2
unnamed: R45.2, R49.2, U5.3
unnamed: JP50.1, R49.1
unnamed: JP41.2, R44.1
unnamed: JP43.2, R45.1
unnamed: C47.2, JP41.3, JP46.1
unnamed: C48.2, JP43.1, JP47.1
unnamed: C49.2, JP44.3, JP48.1
unnamed: JP44.2, R46.1
unnamed: C46.1, R46.2, R50.2, U5.6
unnamed: JP45.2, R47.1
unnamed: C50.2, JP45.1, JP49.1
unnamed: R42.1, R47.2, U5.5
unnamed: JP42.1, R42.2
unnamed: C55.1, R54.2, R58.1, U6.2
unnamed: R55.2, R59.2, U6.3
unnamed: JP60.1, R59.1
unnamed: JP51.2, R54.1
unnamed: JP53.2, R55.1
unnamed: C57.2, JP51.3, JP56.1
unnamed: C58.2, JP53.1, JP57.1
unnamed: C59.2, JP54.3, JP58.1
unnamed: JP54.2, R56.1
unnamed: C56.1, R56.2, R60.2, U6.6
unnamed: JP55.2, R57.1
unnamed: C60.2, JP55.1, JP59.1
unnamed: R52.1, R57.2, U6.5
unnamed: JP52.1, R52.2
unnamed: C65.1, R64.2, R68.1, U7.2
unnamed: R65.2, R69.2, U7.3
unnamed: JP70.1, R69.1
unnamed: JP61.2, R64.1
unnamed: JP63.2, R65.1
unnamed: C67.2, JP61.3, JP66.1
unnamed: C68.2, JP63.1, JP67.1
unnamed: C69.2, JP64.3, JP68.1
unnamed: JP64.2, R66.1
unnamed: C66.1, R66.2, R70.2, U7.6
unnamed: JP65.2, R67.1
unnamed: C70.2, JP65.1, JP69.1
unnamed: R62.1, R67.2, U7.5
unnamed: JP62.1, R62.2
unnamed: C75.1, R74.2, R78.1, U8.2
unnamed: R75.2, R79.2, U8.3
unnamed: JP80.1, R79.1
unnamed: JP71.2, R74.1
unnamed: JP73.2, R75.1
unnamed: C77.2, JP71.3, JP76.1
unnamed: C78.2, JP73.1, JP77.1
unnamed: C79.2, JP74.3, JP78.1
unnamed: JP74.2, R76.1
unnamed: C76.1, R76.2, R80.2, U8.6
unnamed: JP75.2, R77.1
unnamed: C80.2, JP75.1, JP79.1
unnamed: R72.1, R77.2, U8.5
unnamed: JP72.1, R72.2
unnamed: C85.1, R84.2, R88.1, U9.2
unnamed: R85.2, R89.2, U9.3
unnamed: JP90.1, R89.1
unnamed: JP81.2, R84.1
unnamed: JP83.2, R85.1
unnamed: C87.2, JP81.3, JP86.1
unnamed: C88.2, JP83.1, JP87.1
unnamed: C89.2, JP84.3, JP88.1
unnamed: JP84.2, R86.1
unnamed: C86.1, R86.2, R90.2, U9.6
unnamed: JP85.2, R87.1
unnamed: C90.2, JP85.1, JP89.1
unnamed: R82.1, R87.2, U9.5
unnamed: JP82.1, R82.2
unnamed: C95.1, R94.2, R98.1, U10.2
unnamed: R95.2, R99.2, U10.3
unnamed: JP100.1, R99.1
unnamed: JP91.2, R94.1
unnamed: JP93.2, R95.1
unnamed: C97.2, JP91.3, JP96.1
unnamed: C98.2, JP93.1, JP97.1
unnamed: C99.2, JP94.3, JP98.1
unnamed: JP94.2, R96.1
unnamed: C96.1, R96.2, R100.2, U10.6
unnamed: JP95.2, R97.1
unnamed: C100.2, JP95.1, JP99.1
unnamed: R92.1, R97.2, U10.5
unnamed: JP92.1, R92.2
unnamed: C105.1, R104.2, R108.1, U11.2
unnamed: R105.2, R109.2, U11.3
unnamed: JP110.1, R109.1
unnamed: JP101.2, R104.1
unnamed: JP103.2, R105.1
unnamed: C107.2, JP101.3, JP106.1
unnamed: C108.2, JP103.1, JP107.1
unnamed: C109.2, JP104.3, JP108.1
unnamed: JP104.2, R106.1
unnamed: C106.1, R106.2, R110.2, U11.6
unnamed: JP105.2, R107.1
unnamed: C110.2, JP105.1, JP109.1
unnamed: R102.1, R107.2, U11.5
unnamed: JP102.1, R102.2
unnamed: C115.1, R114.2, R118.1, U12.2
unnamed: R115.2, R119.2, U12.3
unnamed: JP120.1, R119.1
unnamed: JP111.2, R114.1
unnamed: JP113.2, R115.1
unnamed: C117.2, JP111.3, JP116.1
unnamed: C118.2, JP113.1, JP117.1
unnamed: C119.2, JP114.3, JP118.1
unnamed: JP114.2, R116.1
unnamed: C116.1, R116.2, R120.2, U12.6
unnamed: JP115.2, R117.1
unnamed: C120.2, JP115.1, JP119.1
unnamed: R112.1, R117.2, U12.5
unnamed: JP112.1, R112.2
unnamed: C125.1, R124.2, R128.1, U13.2
unnamed: R125.2, R129.2, U13.3
unnamed: JP130.1, R129.1
unnamed: JP121.2, R124.1
unnamed: JP123.2, R125.1
unnamed: C127.2, JP121.3, JP126.1
unnamed: C128.2, JP123.1, JP127.1
unnamed: C129.2, JP124.3, JP128.1
unnamed: JP124.2, R126.1
unnamed: C126.1, R126.2, R130.2, U13.6
unnamed: JP125.2, R127.1
unnamed: C130.2, JP125.1, JP129.1
unnamed: R122.1, R127.2, U13.5
unnamed: JP122.1, R122.2
unnamed: C135.1, R134.2, R138.1, U14.2
unnamed: R135.2, R139.2, U14.3
unnamed: JP140.1, R139.1
unnamed: JP131.2, R134.1
unnamed: JP133.2, R135.1
unnamed: C137.2, JP131.3, JP136.1
unnamed: C138.2, JP133.1, JP137.1
unnamed: C139.2, JP134.3, JP138.1
unnamed: JP134.2, R136.1
unnamed: C136.1, R136.2, R140.2, U14.6
unnamed: JP135.2, R137.1
unnamed: C140.2, JP135.1, JP139.1
unnamed: R132.1, R137.2, U14.5
unnamed: JP132.1, R132.2
unnamed: C145.1, R144.2, R148.1, U15.2
unnamed: R145.2, R149.2, U15.3
unnamed: JP150.1, R149.1
unnamed: JP141.2, R144.1
unnamed: JP143.2, R145.1
unnamed: C147.2, JP141.3, JP146.1
unnamed: C148.2, JP143.1, JP147.1
unnamed: C149.2, JP144.3, JP148.1
unnamed: JP144.2, R146.1
unnamed: C146.1, R146.2, R150.2, U15.6
unnamed: JP145.2, R147.1
unnamed: C150.2, JP145.1, JP149.1
unnamed: R142.1, R147.2, U15.5
unnamed: JP142.1, R142.2
unnamed: C155.1, R154.2, R158.1, U16.2
unnamed: R155.2, R159.2, U16.3
unnamed: JP160.1, R159.1
unnamed: JP151.2, R154.1
unnamed: JP153.2, R155.1
unnamed: C157.2, JP151.3, JP156.1
unnamed: C158.2, JP153.1, JP157.1
unnamed: C159.2, JP154.3, JP158.1
unnamed: JP154.2, R156.1
unnamed: C156.1, R156.2, R160.2, U16.6
unnamed: JP155.2, R157.1
unnamed: C160.2, JP155.1, JP159.1
unnamed: R152.1, R157.2, U16.5
unnamed: JP152.1, R152.2
unnamed: C165.1, R164.2, R168.1, U17.2
unnamed: R165.2, R169.2, U17.3
unnamed: JP170.1, R169.1
unnamed: JP161.2, R164.1
unnamed: JP163.2, R165.1
unnamed: C167.2, JP161.3, JP166.1
unnamed: C168.2, JP163.1, JP167.1
unnamed: C169.2, JP164.3, JP168.1
unnamed: JP164.2, R166.1
unnamed: C166.1, R166.2, R170.2, U17.6
unnamed: JP165.2, R167.1
unnamed: C170.2, JP165.1, JP169.1
unnamed: R162.1, R167.2, U17.5
unnamed: JP162.1, R162.2
unnamed: C175.1, R174.2, R178.1, U18.2
unnamed: R175.2, R179.2, U18.3
unnamed: JP180.1, R179.1
unnamed: JP171.2, R174.1
unnamed: JP173.2, R175.1
unnamed: C177.2, JP171.3, JP176.1
unnamed: C178.2, JP173.1, JP177.1
unnamed: C179.2, JP174.3, JP178.1
unnamed: JP174.2, R176.1
unnamed: C176.1, R176.2, R180.2, U18.6
unnamed: JP175.2, R177.1
unnamed: C180.2, JP175.1, JP179.1
unnamed: R172.1, R177.2, U18.5
unnamed: JP172.1, R172.2
unnamed: C185.1, R184.2, R188.1, U19.2
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

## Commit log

2018-06-08 Schematic done, in the middle of layout.
    [TSH82_Configurable_Op_Amp_Board.brd, TSH82_Configurable_Op_Amp_Board.sch]
2018-07-05 Close to done, labels, layout, etc.
    [TSH82_Configurable_Op_Amp_Board.brd, TSH82_Configurable_Op_Amp_Board.sch]
2018-07-18 Ready for review.
    [Board_Design_Checklist_TSH82_Configurable_OpAmp_Board_.xls, TSH82_Configurable_Op_Amp_Board.brd, TSH82_Configurable_Op_Amp_Board.sch]
2018-07-23 Changes post design review.
    [TSH82_Configurable_Op_Amp_Board.brd, TSH82_Configurable_Op_Amp_Board.sch]
2018-08-20 Pushed the power trace out a bit and added some ground vias.
    [TSH82_Configurable_Op_Amp_Board.brd]
2018-08-23 Add bottom fiducials, move a trace, increment version, remove extra files.
    [Board_Design_Checklist_TSH82_Configurable_OpAmp_Board_.xls, TSH82_Configurable_Op_Amp_Board.brd, TSH82_Configurable_Op_Amp_Board.sch]
2018-09-11 created panel v10
    [14049-TSH82_Configurable_Op_Amp_Board-Panel.TXT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]

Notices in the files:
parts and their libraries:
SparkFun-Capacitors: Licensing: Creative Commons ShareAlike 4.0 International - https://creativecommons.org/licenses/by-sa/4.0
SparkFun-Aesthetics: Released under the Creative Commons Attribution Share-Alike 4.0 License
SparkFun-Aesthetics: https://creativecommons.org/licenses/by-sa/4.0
